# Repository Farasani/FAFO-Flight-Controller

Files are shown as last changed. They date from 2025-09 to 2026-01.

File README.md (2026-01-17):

# FAFO

<picture>
  <source media="(prefers-color-scheme: dark)" width=60% height=60% srcset="https://github.com/user-attachments/assets/f2668aae-5746-43aa-aec3-286b064c4626">
  <source media="(prefers-color-scheme: light)" width=60% height=60% srcset="https://github.com/user-attachments/assets/a5b0ae70-b65e-41dd-a281-93c37e5f3b0a">
  Shows a black logo in light color mode and a white one in dark color mode.
</picture>

F4 Flight Controller for quadcopter, hecxacopter and fixed wings drones.

## Specs

- 168MHz STM32F405RGT6
- 5x UARTS serial ports
- I2C1
- 6-Axis ICM-42688-P
- MAX7456 OSD
- BMP280 Barometer
- 1GB BlackBox
- 6 PWM/DSHOT outputs

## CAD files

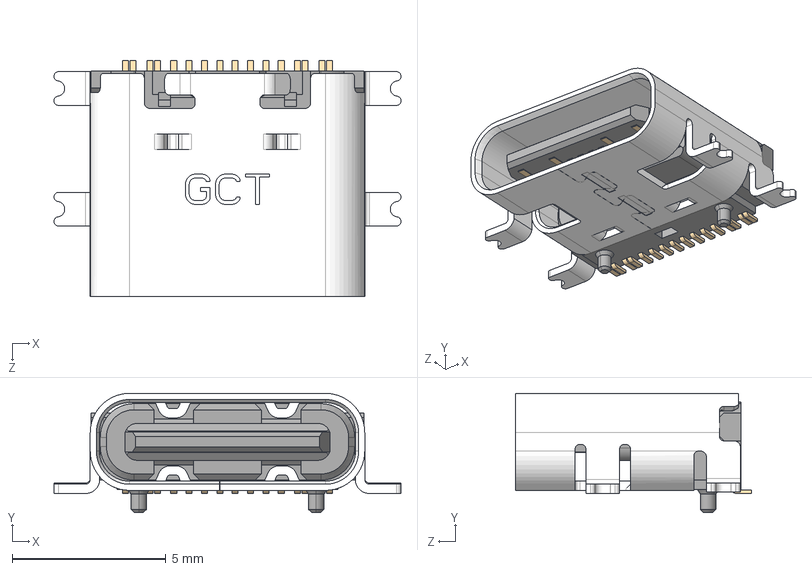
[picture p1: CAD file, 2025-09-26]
3DModels/USB4110GFA--3DModel-STEP-269445.STEP
11.3 x 3.89 x 7.70 mm

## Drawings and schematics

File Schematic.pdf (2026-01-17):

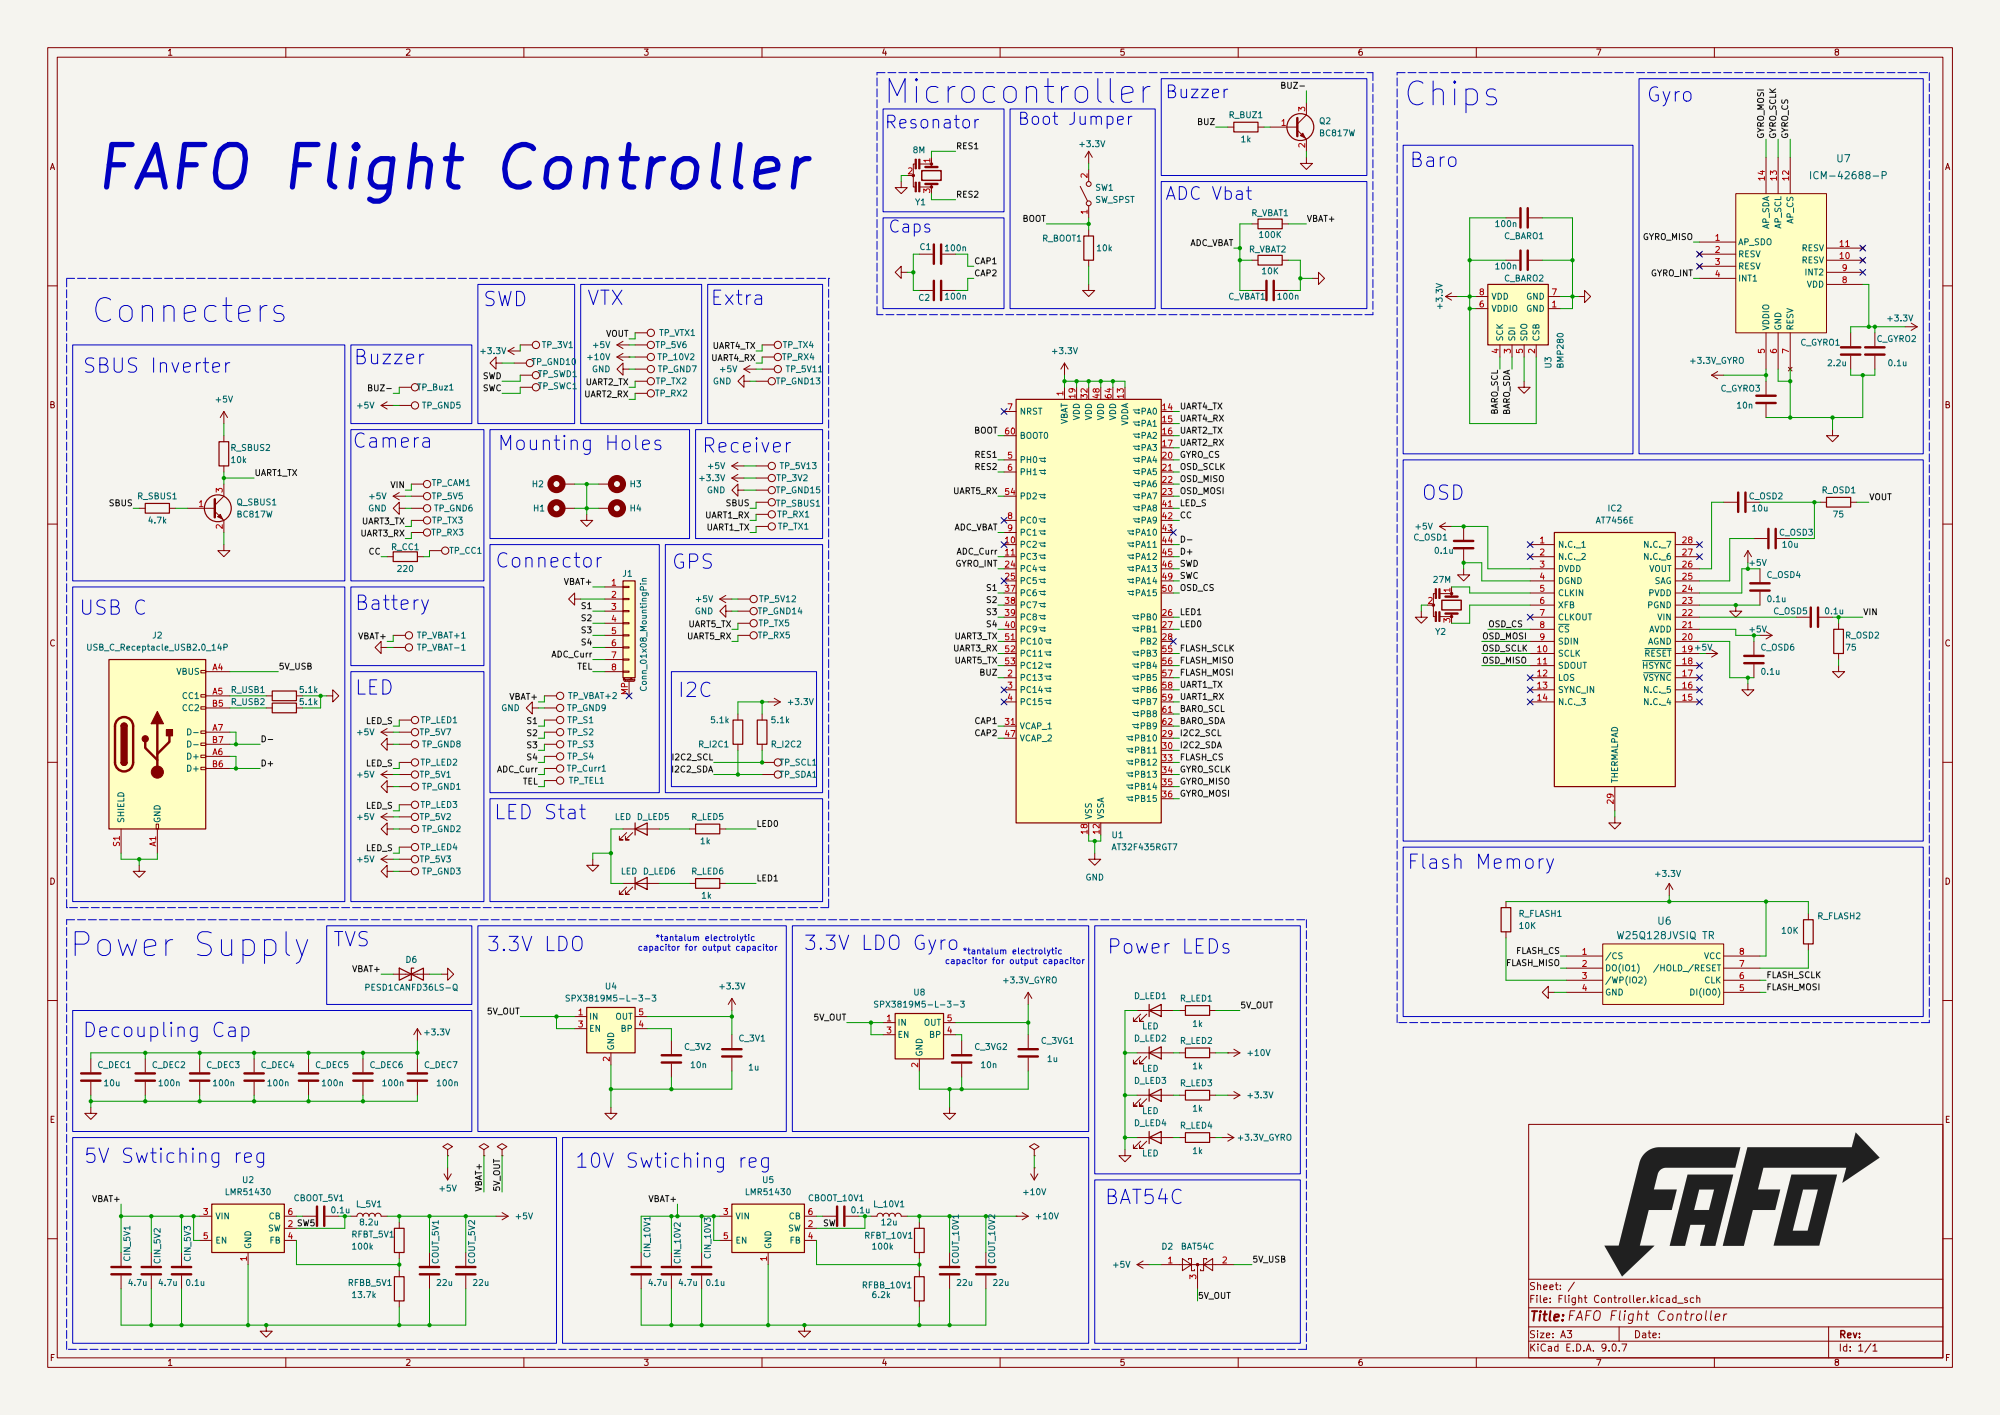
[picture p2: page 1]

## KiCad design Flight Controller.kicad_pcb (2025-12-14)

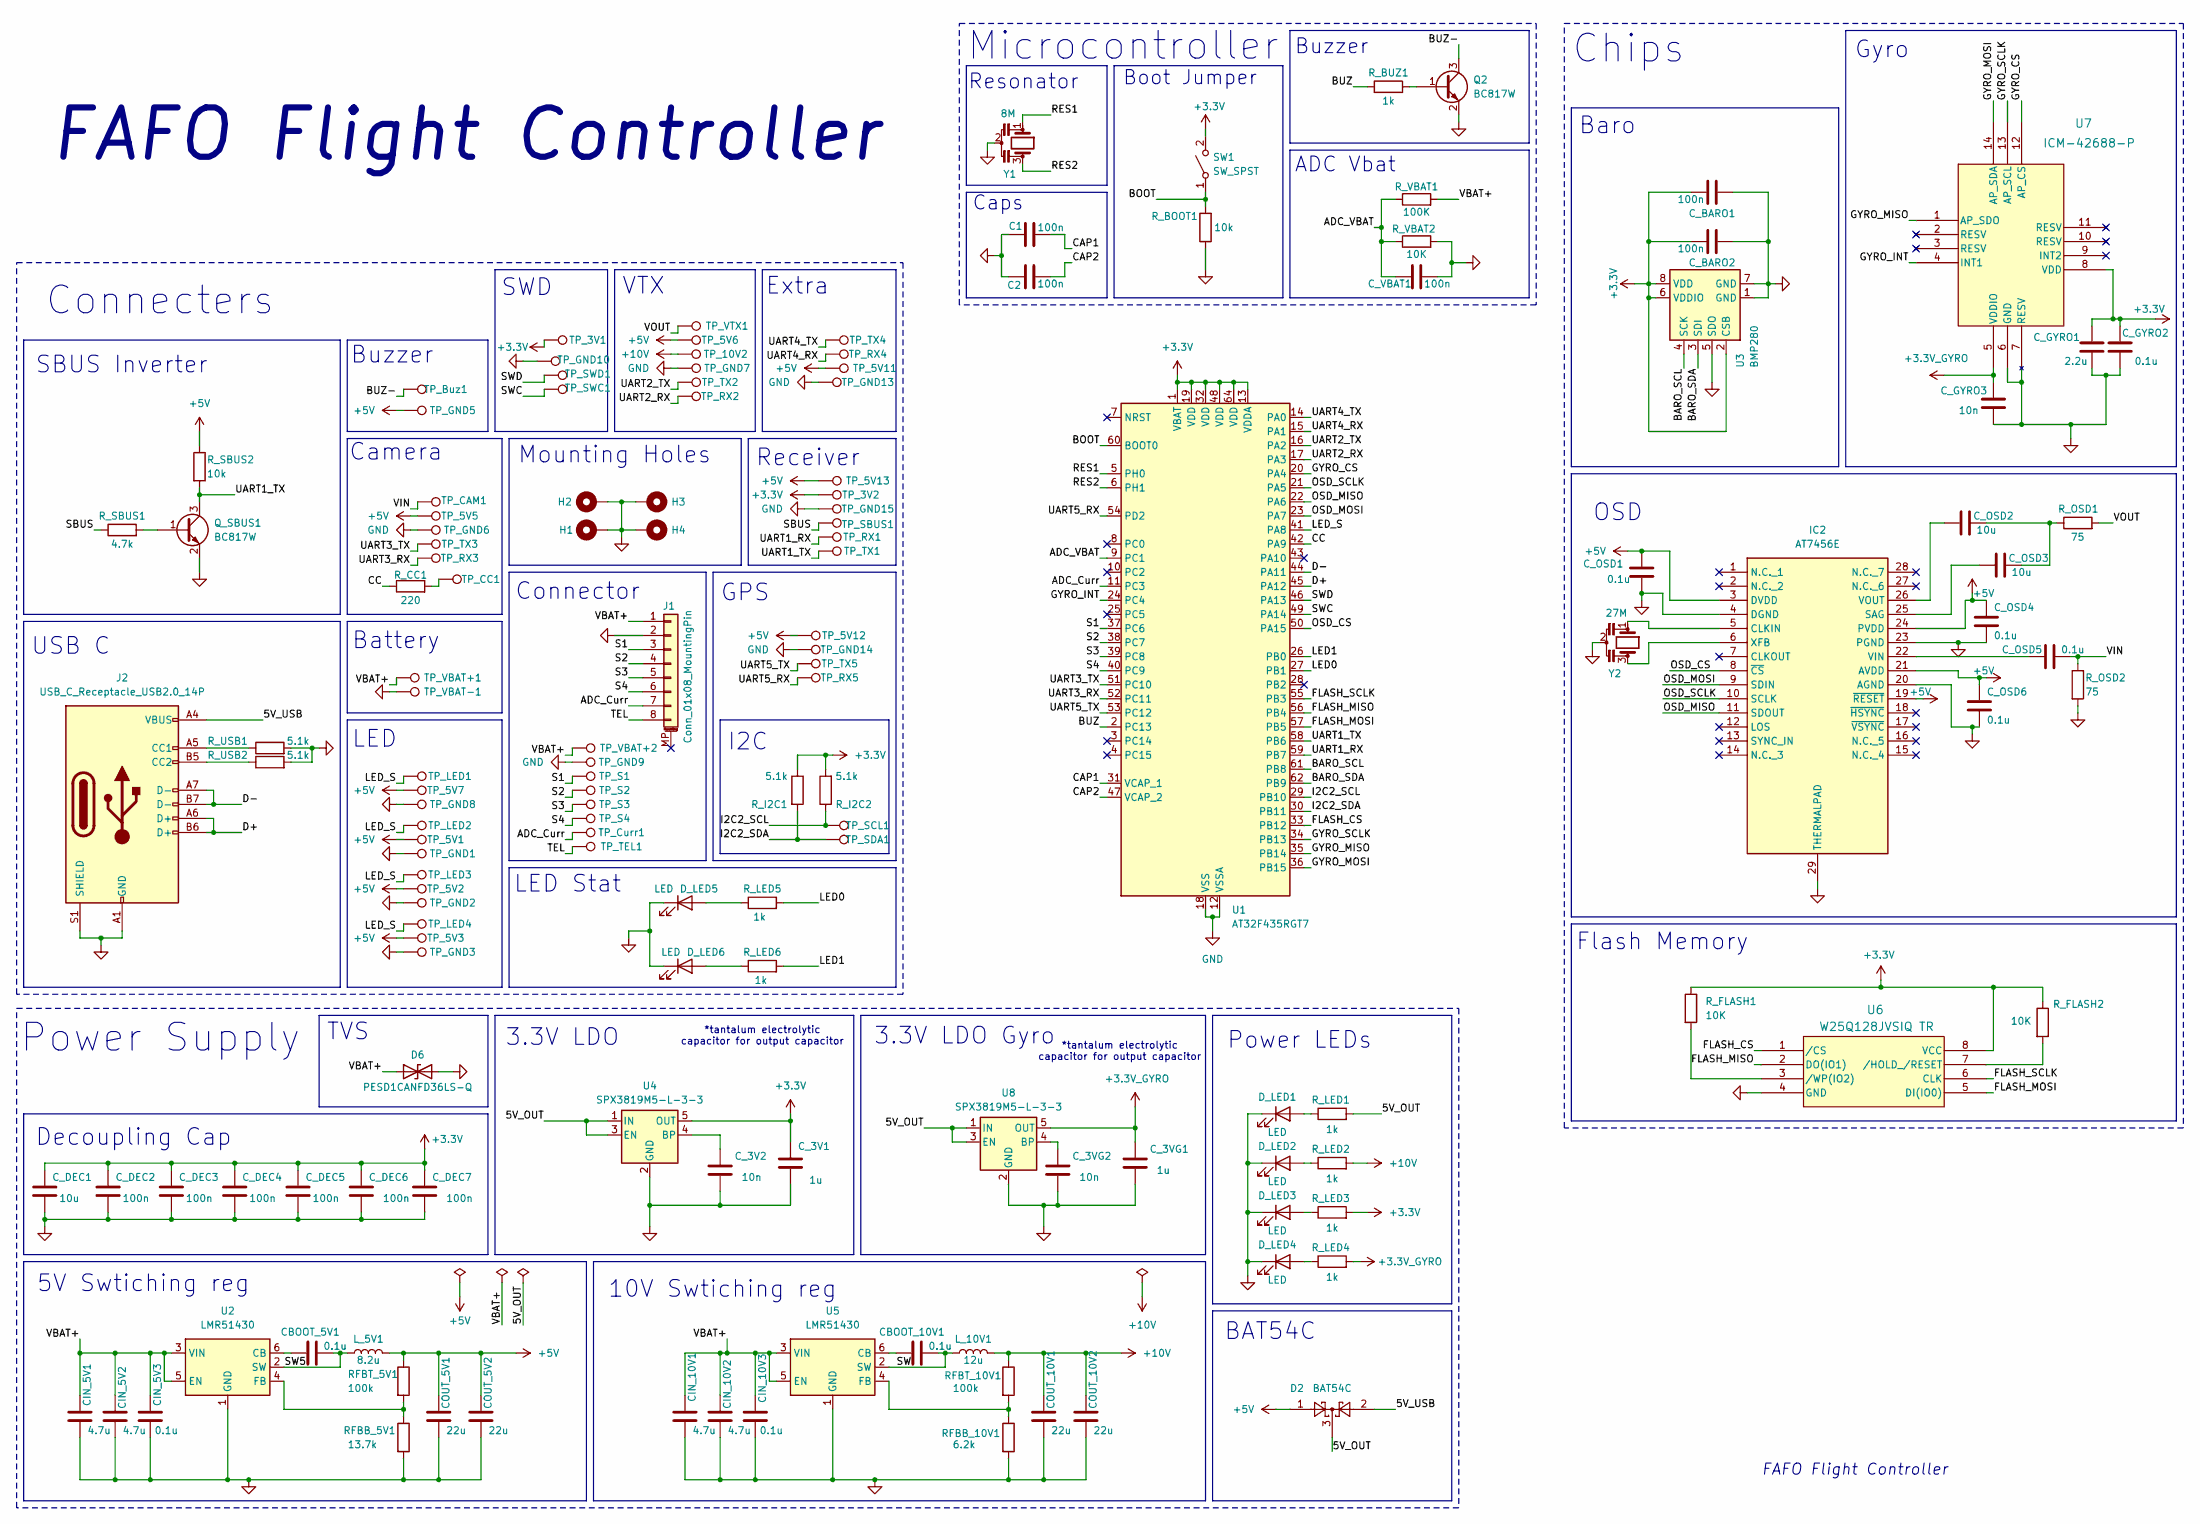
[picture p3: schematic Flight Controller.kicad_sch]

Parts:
C1, C2: 100n; C_0402_1005Metric
CBOOT_5V1, CBOOT_10V1: 0.1u; C_0603_1608Metric
CIN_5V1, CIN_5V2, CIN_10V1, CIN_10V2: 4.7u; C_0805_2012Metric
CIN_5V3, CIN_10V3: 0.1u; C_0402_1005Metric
COUT_5V1, COUT_5V2, COUT_10V1, COUT_10V2: 22u; C_0805_2012Metric
C_3V1, C_3VG1: 1u; C_0603_1608Metric
C_3V2, C_3VG2: 10n; C_0402_1005Metric
C_BARO1, C_BARO2: 100n; C_0402_1005Metric
C_DEC1: 10u; C_0603_1608Metric
C_DEC2, C_DEC3, C_DEC4, C_DEC5, C_DEC6, C_DEC7: 100n; C_0402_1005Metric
C_GYRO1: 2.2u; C_0402_1005Metric
C_GYRO2: 0.1u; C_0402_1005Metric
C_GYRO3: 10n; C_0402_1005Metric
C_OSD1, C_OSD4, C_OSD5, C_OSD6: 0.1u; C_0402_1005Metric
C_OSD2, C_OSD3: 10u; C_0402_1005Metric
C_VBAT1: 100n; C_0402_1005Metric
D2: BAT54C; SOT-23
D6: PESD1CANFD36LS-Q; D_SOD-882
D_LED1, D_LED2, D_LED3, D_LED4, D_LED5, D_LED6: LED; LED_0603_1608Metric
H1, H2, H3, H4: MountingHole_Pad; MountingHole_3.2mm_M3_DIN965_Pad
IC2: AT7456E; SOP65P637X110-28N; Manufacturer_Part_Number AT7456E
J1: Conn_01x08_MountingPin; JST_SH_SM08B-SRSS-TB_1x08-1MP_P1.00mm_Horizontal
J2: USB_C_Receptacle_USB2.0_14P; USB_C_Receptacle_GCT_USB4110
L_5V1: 8.2u; L_Vishay_IHLP-2525
L_10V1: 12u; 744393465120
Q2: BC817W; SOT-323_SC-70
Q_SBUS1: BC817W; SOT-323_SC-70
RFBB_5V1: 13.7k; R_0402_1005Metric
RFBB_10V1: 6.2k; R_0402_1005Metric
RFBT_5V1, RFBT_10V1: 100k; R_0402_1005Metric
R_BOOT1: 10k; R_0402_1005Metric
R_BUZ1: 1k; R_0402_1005Metric
R_CC1: 220; R_0402_1005Metric
R_FLASH1, R_FLASH2: 10K; R_0402_1005Metric
R_I2C1, R_I2C2: 5.1k; R_0402_1005Metric
R_LED1, R_LED2, R_LED3, R_LED4, R_LED5, R_LED6: 1k; R_0603_1608Metric
R_OSD1, R_OSD2: 75; R_0603_1608Metric
R_SBUS1: 4.7k; R_0805_2012Metric
R_SBUS2: 10k; R_0603_1608Metric
R_USB1, R_USB2: 5.1k; R_0603_1608Metric
R_VBAT1: 100K; R_0805_2012Metric
R_VBAT2: 10K; R_1206_3216Metric
SW1: SW_SPST; SW_SPST_EVQP2_MiddlePushTravel_H2.5mm
TP_3V1, TP_3V2, TP_5V1, TP_5V2, TP_5V3, TP_5V5, TP_5V6, TP_5V7, TP_5V11, TP_5V12, TP_5V13, TP_10V2: TestPoint; Solder_Pad_SMD
TP_Buz1: TestPoint; Solder_Pad_SMD
TP_CAM1: TestPoint; Solder_Pad_SMD
TP_CC1: TestPoint; Solder_Pad_SMD
TP_Curr1: TestPoint; Solder_Pad_SMD_Half
TP_GND1, TP_GND2, TP_GND3, TP_GND5, TP_GND6, TP_GND7, TP_GND8, TP_GND10, TP_GND13, TP_GND14, TP_GND15: TestPoint; Solder_Pad_SMD
TP_GND9: TestPoint; Solder_Pad_SMD_Half
TP_LED1, TP_LED2, TP_LED3, TP_LED4: TestPoint; Solder_Pad_SMD
TP_RX1, TP_RX2, TP_RX3, TP_RX4, TP_RX5: TestPoint; Solder_Pad_SMD
TP_S1, TP_S2, TP_S3, TP_S4: TestPoint; Solder_Pad_SMD_Half
TP_SBUS1: TestPoint; Solder_Pad_SMD
TP_SCL1: TestPoint; Solder_Pad_SMD
TP_SDA1: TestPoint; Solder_Pad_SMD
TP_SWC1: TestPoint; Solder_Pad_SMD
TP_SWD1: TestPoint; Solder_Pad_SMD
TP_TEL1: TestPoint; Solder_Pad_SMD_Half
TP_TX1, TP_TX2, TP_TX3, TP_TX4, TP_TX5: TestPoint; Solder_Pad_SMD
TP_VBAT+1: TestPoint; Solder_Pad_SMD
TP_VBAT+2: TestPoint; Solder_Pad_SMD_Half
TP_VBAT-1: TestPoint; Solder_Pad_SMD
TP_VTX1: TestPoint; Solder_Pad_SMD
U1: AT32F435RGT7; LQFP-64_10x10mm_P0.5mm
U2, U5: LMR51430; SOT-23-6
U3: BMP280; Bosch_LGA-8_2x2.5mm_P0.65mm_ClockwisePinNumbering
U4, U8: SPX3819M5-L-3-3; SOT-23-5
U6: W25Q128JVSIQ TR; SOIC_208MIL_WIN
U7: ICM-42688-P; Bosch_LGA-14_3x2.5mm_P0.5mm
Y1: 8M; Resonator_SMD_Murata_CSTxExxV-3Pin_3.0x1.1mm
Y2: 27M; E2X270061X04

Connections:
+3.3V: C_3V1.1, C_BARO1.2, C_BARO2.2, C_DEC1.1, C_DEC2.1, C_DEC3.1, C_DEC4.1, C_DEC5.1, C_DEC6.1, C_DEC7.1, C_GYRO1.1, C_GYRO2.1, R_FLASH1.1, R_FLASH2.1, R_I2C1.1, R_I2C2.2, R_LED3.2, SW1.2 (B), TP_3V1.1, TP_3V2.1, U1.1 (VBAT), U1.13 (VDDA), U1.19 (VDD), U1.32 (VDD), U1.48 (VDD), U1.64 (VDD), U3.2 (CSB), U3.6 (VDDIO), U3.8 (VDD), U4.5 (OUT), U6.8 (VCC), U7.8 (VDD)
+3.3V_GYRO: C_3VG1.1, C_GYRO3.1, R_LED4.2, U7.5 (VDDIO), U8.5 (OUT)
+5V: COUT_5V1.1, COUT_5V2.1, C_OSD1.1, C_OSD4.1, C_OSD6.1, D2.1, IC2.3 (DVDD), IC2.19 (~RESET), IC2.21 (AVDD), IC2.24 (PVDD), L_5V1.2, RFBT_5V1.1, R_SBUS2.1, TP_5V1.1, TP_5V2.1, TP_5V3.1, TP_5V5.1, TP_5V6.1, TP_5V7.1, TP_5V11.1, TP_5V12.1, TP_5V13.1, TP_GND5.1
+10V: COUT_10V1.1, COUT_10V2.1, L_10V1.2, RFBT_10V1.1, R_LED2.2, TP_10V2.1
/5V_OUT: D2.3, R_LED1.2, U4.1 (IN), U4.3 (EN), U8.1 (IN), U8.3 (EN)
/5V_USB: D2.2, J2.A4 (VBUS), J2.A9 (VBUS), J2.B4 (VBUS), J2.B9 (VBUS)
/ADC_Curr: J1.7, TP_Curr1.1, U1.11 (PC3)
/ADC_VBAT: C_VBAT1.2, R_VBAT1.1, R_VBAT2.1, U1.9 (PC1)
/BARO_SCL: U1.61 (PB8), U3.4 (SCK)
/BARO_SDA: U1.62 (PB9), U3.3 (SDI)
/BOOT: R_BOOT1.2, SW1.1 (A), U1.60 (BOOT0)
/BUZ: R_BUZ1.1, U1.2 (PC13)
/BUZ-: Q2.3 (C), TP_Buz1.1
/CAP1: C1.2, U1.31 (VCAP_1)
/CAP2: C2.2, U1.47 (VCAP_2)
/CC: R_CC1.1, U1.42 (PA9)
/D+: J2.A6 (D+), J2.B6 (D+), U1.45 (PA12)
/D-: J2.A7 (D-), J2.B7 (D-), U1.44 (PA11)
/FLASH_CS: U1.33 (PB12), U6.1 (/CS)
/FLASH_MISO: U1.56 (PB4), U6.2 (DO(IO1))
/FLASH_MOSI: U1.57 (PB5), U6.5 (DI(IO0))
/FLASH_SCLK: U1.55 (PB3), U6.6 (CLK)
/GYRO_CS: U1.20 (PA4), U7.12 (AP_CS)
/GYRO_INT: U1.24 (PC4), U7.4 (INT1)
/GYRO_MISO: U1.35 (PB14), U7.1 (AP_SDO)
/GYRO_MOSI: U1.36 (PB15), U7.14 (AP_SDA)
/GYRO_SCLK: U1.34 (PB13), U7.13 (AP_SCL)
/I2C2_SCL: R_I2C2.1, TP_SCL1.1, U1.29 (PB10)
/I2C2_SDA: R_I2C1.2, TP_SDA1.1, U1.30 (PB11)
/LED0: R_LED5.2, U1.27 (PB1)
/LED1: R_LED6.2, U1.26 (PB0)
/LED_S: TP_LED1.1, TP_LED2.1, TP_LED3.1, TP_LED4.1, U1.41 (PA8)
/OSD_CS: IC2.8 (~CS), U1.50 (PA15)
/OSD_MISO: IC2.11 (SDOUT), U1.22 (PA6)
/OSD_MOSI: IC2.9 (SDIN), U1.23 (PA7)
/OSD_SCLK: IC2.10 (SCLK), U1.21 (PA5)
/RES1: U1.5 (PH0), Y1.1
/RES2: U1.6 (PH1), Y1.3
/S1: J1.3, TP_S1.1, U1.37 (PC6)
/S2: J1.4, TP_S2.1, U1.38 (PC7)
/S3: J1.5, TP_S3.1, U1.39 (PC8)
/S4: J1.6, TP_S4.1, U1.40 (PC9)
/SBUS: R_SBUS1.1, TP_SBUS1.1
/SW: CBOOT_10V1.2, L_10V1.1, U5.2 (SW)
/SW5: CBOOT_5V1.2, L_5V1.1, U2.2 (SW)
/SWC: TP_SWC1.1, U1.49 (PA14)
/SWD: TP_SWD1.1, U1.46 (PA13)
/TEL: J1.8, TP_TEL1.1
/UART1_RX: TP_RX1.1, U1.59 (PB7)
/UART1_TX: Q_SBUS1.3 (C), R_SBUS2.2, TP_TX1.1, U1.58 (PB6)
/UART2_RX: TP_RX2.1, U1.17 (PA3)
/UART2_TX: TP_TX2.1, U1.16 (PA2)
/UART3_RX: TP_RX3.1, U1.52 (PC11)
/UART3_TX: TP_TX3.1, U1.51 (PC10)
/UART4_RX: TP_RX4.1, U1.15 (PA1)
/UART4_TX: TP_TX4.1, U1.14 (PA0)
/UART5_RX: TP_RX5.1, U1.54 (PD2)
/UART5_TX: TP_TX5.1, U1.53 (PC12)
/VBAT+: CIN_5V1.1, CIN_5V2.1, CIN_5V3.2, CIN_10V1.1, CIN_10V2.1, CIN_10V3.2, D6.1 (A1), J1.1, R_VBAT1.2, TP_VBAT+1.1, TP_VBAT+2.1, U2.3 (VIN), U2.5 (EN), U5.3 (VIN), U5.5 (EN)
/VIN: C_OSD5.2, R_OSD2.1, TP_CAM1.1
/VOUT: R_OSD1.2, TP_VTX1.1
GND: C1.1, C2.1, CIN_5V1.2, CIN_5V2.2, CIN_5V3.1, CIN_10V1.2, CIN_10V2.2, CIN_10V3.1, COUT_5V1.2, COUT_5V2.2, COUT_10V1.2, COUT_10V2.2, C_3V1.2, C_3V2.2, C_3VG1.2, C_3VG2.2, C_BARO1.1, C_BARO2.1, C_DEC1.2, C_DEC2.2, C_DEC3.2, C_DEC4.2, C_DEC5.2, C_DEC6.2, C_DEC7.2, C_GYRO1.2, C_GYRO2.2, C_GYRO3.2, C_OSD1.2, C_OSD4.2, C_OSD6.2, C_VBAT1.1, D6.2 (A2), D_LED1.1 (K), D_LED2.1 (K), D_LED3.1 (K), D_LED4.1 (K), D_LED5.1 (K), D_LED6.1 (K), H1.1, H2.1, H3.1, H4.1, IC2.4 (DGND), IC2.20 (AGND), IC2.23 (PGND), IC2.29 (THERMALPAD), J1.2, J2.A1 (GND), J2.A12 (GND), J2.B1 (GND), J2.B12 (GND), J2.S1 (SHIELD), Q2.2 (E), Q_SBUS1.2 (E), RFBB_5V1.2, RFBB_10V1.2, R_BOOT1.1, R_OSD2.2, R_USB1.2, R_USB2.2, R_VBAT2.2, TP_GND1.1, TP_GND2.1, TP_GND3.1, TP_GND6.1, TP_GND7.1, TP_GND8.1, TP_GND9.1, TP_GND10.1, TP_GND13.1, TP_GND14.1, TP_GND15.1, TP_VBAT-1.1, U1.12 (VSSA), U1.18 (VSS), U1.63 (VSS), U2.1 (GND), U3.1 (GND), U3.5 (SDO), U3.7 (GND), U4.2 (GND), U5.1 (GND), U6.4 (GND), U7.6 (GND), U7.7 (RESV), U8.2 (GND), Y1.2, Y2.2
unnamed: C_OSD2.2, C_OSD3.2, R_OSD1.1
unnamed: D_LED1.2 (A), R_LED1.1
unnamed: D_LED2.2 (A), R_LED2.1
unnamed: D_LED3.2 (A), R_LED3.1
unnamed: D_LED4.2 (A), R_LED4.1
unnamed: D_LED5.2 (A), R_LED5.1
unnamed: D_LED6.2 (A), R_LED6.1
unnamed: IC2.5 (CLKIN), Y2.1
unnamed: C_OSD3.1, IC2.25 (SAG)
unnamed: C_OSD5.1, IC2.22 (VIN)
unnamed: C_OSD2.1, IC2.26 (VOUT)
unnamed: IC2.6 (XFB), Y2.3
unnamed: J2.A5 (CC1), R_USB1.1
unnamed: J2.B5 (CC2), R_USB2.1
unnamed: Q2.1 (B), R_BUZ1.2
unnamed: Q_SBUS1.1 (B), R_SBUS1.2
unnamed: R_CC1.2, TP_CC1.1
unnamed: CBOOT_5V1.1, U2.6 (CB)
unnamed: RFBB_5V1.1, RFBT_5V1.2, U2.4 (FB)
unnamed: C_3V2.1, U4.4 (BP)
unnamed: CBOOT_10V1.1, U5.6 (CB)
unnamed: RFBB_10V1.1, RFBT_10V1.2, U5.4 (FB)
unnamed: R_FLASH2.2, U6.7 (/HOLD_/RESET)
unnamed: R_FLASH1.2, U6.3 (/WP(IO2))
unnamed: C_3VG2.1, U8.4 (BP)

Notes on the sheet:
LED
Receiver
SBUS Inverter
Buzzer
Extra
FAFO Flight Controller
Battery
SWD
*tantalum electrolytic capacitor for output capacitor
Resonator
Decoupling Cap
Mounting Holes
3.3V LDO Gyro
Camera
Baro
Gyro
3.3V LDO
Caps
Microcontroller
Flash Memory
GPS
USB C
10V Swtiching reg
I2C
TVS
Power LEDs
Connector
BAT54C
VTX
Power Supply
Boot Jumper
LED Stat
ADC Vbat
5V Swtiching reg
OSD
Connecters
Chips

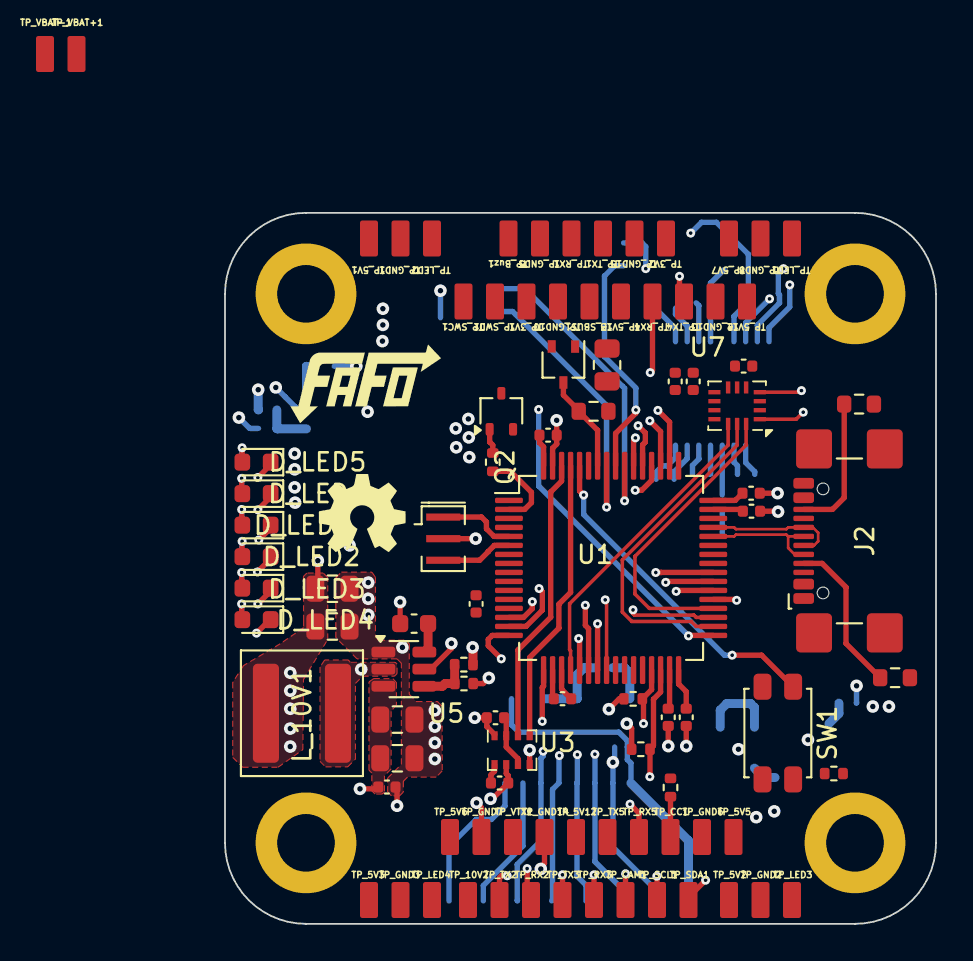
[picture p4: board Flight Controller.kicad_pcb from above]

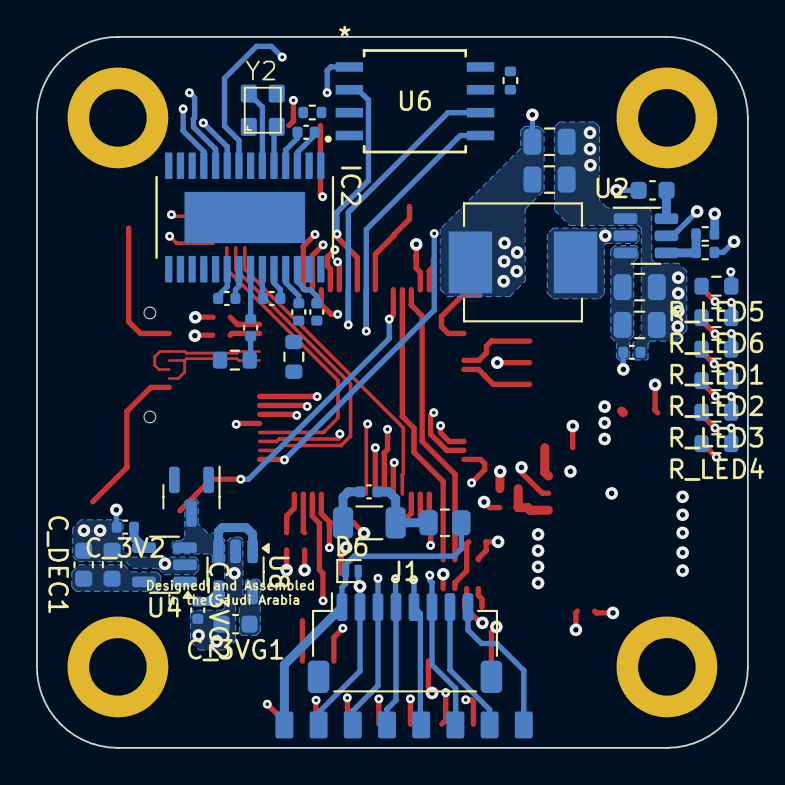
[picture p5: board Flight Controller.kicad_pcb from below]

Board: 6 copper layers, 39.5 x 39.5 mm, 147 parts (50 on the bottom side), 87 nets.

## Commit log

2024-04-01 added Kicad files
    [Flight Controller.kicad_pcb, Flight Controller.kicad_sch]
2024-04-08 schematic update
    [Flight Controller.kicad_sch]
2024-04-16 Update Schematic
    [Flight Controller.kicad_sch]
2024-08-04 Updated Schematics
2025-01-04 Finshed Schematics and started with layout
    [Flight Controller.kicad_pcb, Flight Controller.kicad_sch]
2025-08-21 Layout Update
    [Flight Controller.kicad_pcb]
2025-08-25 Power Supply Sch Udpate
    [Flight Controller.kicad_sch]
2025-08-30 Changes to compline with Betaflighe guidlines
    [Flight Controller.kicad_sch]
2025-09-08 assgining new pins
    [Flight Controller.kicad_sch]
2025-09-09 Power Supply Updates
    [Flight Controller.kicad_sch]
2025-09-10 New connectors
    [Flight Controller.kicad_sch]
2025-09-18 I hope I'm done here with the sch
    [Flight Controller.kicad_sch]
2025-09-18 This time I'm done fr
    [Flight Controller.kicad_sch]
2025-09-18 I'm losing it
    [Flight Controller.kicad_sch]
2025-09-19 Updated naming system
    [Flight Controller.kicad_sch]
2025-09-19 I'm losing it again
    [Flight Controller.kicad_sch]
2025-09-20 One day this will be over
    [Flight Controller.kicad_sch]
2025-09-20 Footprint Assignment Done
    [Flight Controller.kicad_sch]
2025-09-20 Updated Layout
    [Flight Controller.kicad_pcb]
2025-09-21 First Layout
    [Flight Controller.kicad_pcb, Flight Controller.kicad_sch]
2025-09-25 Changed LDOs
    [Flight Controller.kicad_pcb, Flight Controller.kicad_sch]
2025-09-26 Layout Updates
    [Flight Controller.kicad_pcb, Flight Controller.kicad_sch, USB4110GFA--3DModel-STEP-269445.STEP]
2025-10-20 We are going 6 layers BABYYgit add --all!
    [Flight Controller.kicad_pcb]
2025-10-24 Power Supply Layout
    [Flight Controller.kicad_pcb, Flight Controller.kicad_sch]
